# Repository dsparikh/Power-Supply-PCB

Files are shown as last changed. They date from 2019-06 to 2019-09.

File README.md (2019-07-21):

# Power-Supply-PCB
A custom 60W (0-24V @ 2.5A) portable power supply

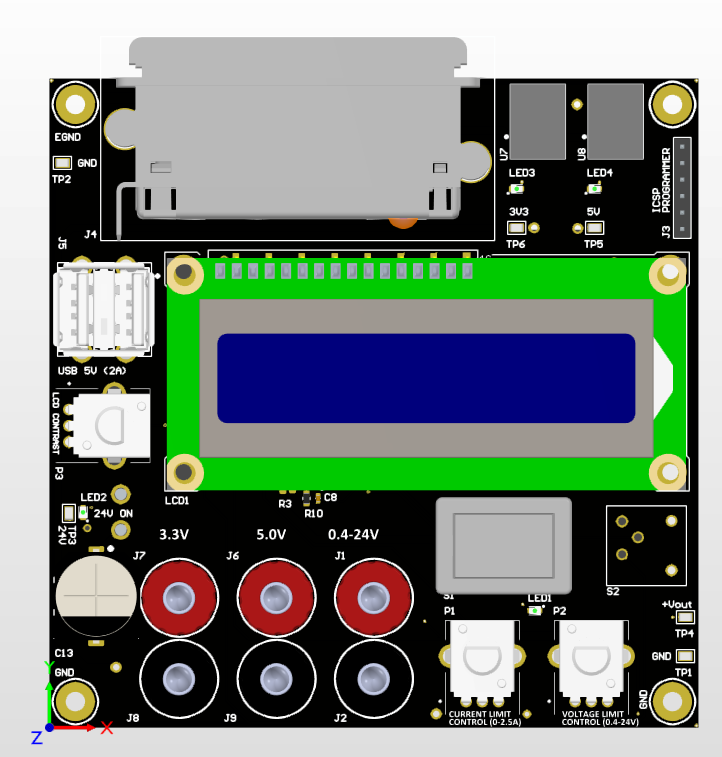
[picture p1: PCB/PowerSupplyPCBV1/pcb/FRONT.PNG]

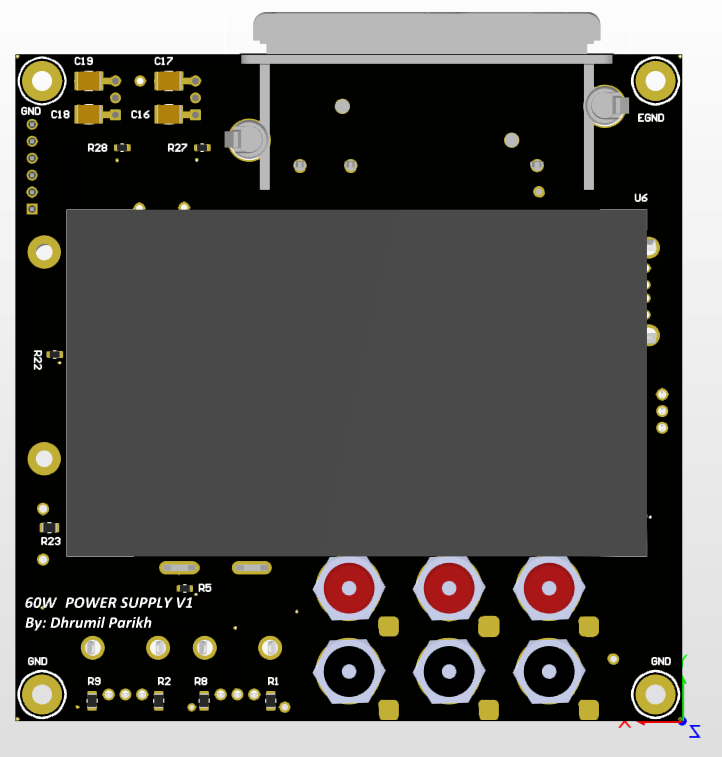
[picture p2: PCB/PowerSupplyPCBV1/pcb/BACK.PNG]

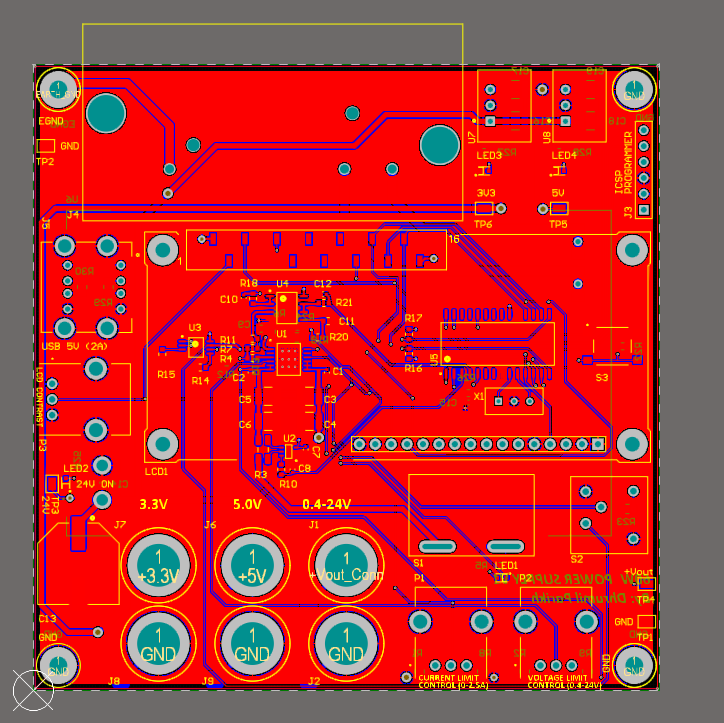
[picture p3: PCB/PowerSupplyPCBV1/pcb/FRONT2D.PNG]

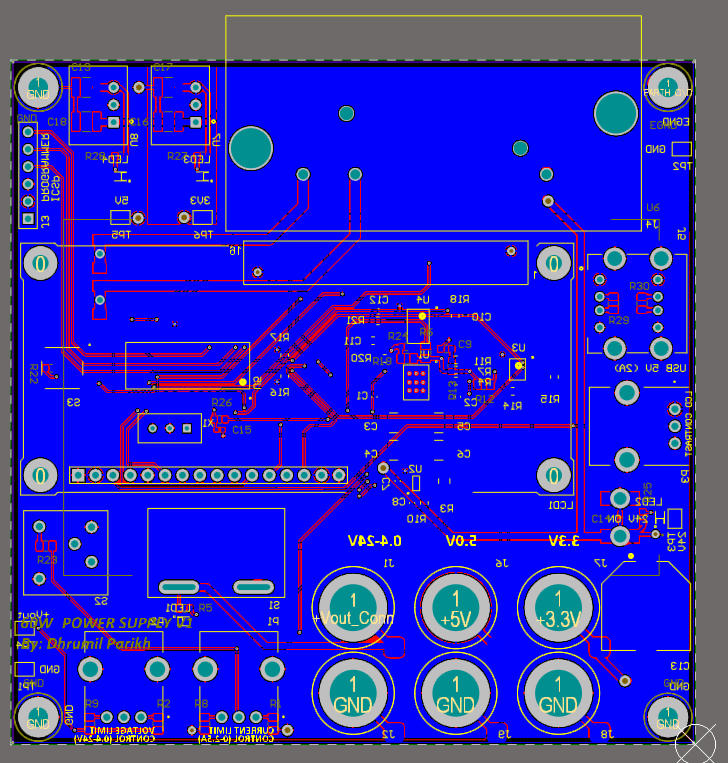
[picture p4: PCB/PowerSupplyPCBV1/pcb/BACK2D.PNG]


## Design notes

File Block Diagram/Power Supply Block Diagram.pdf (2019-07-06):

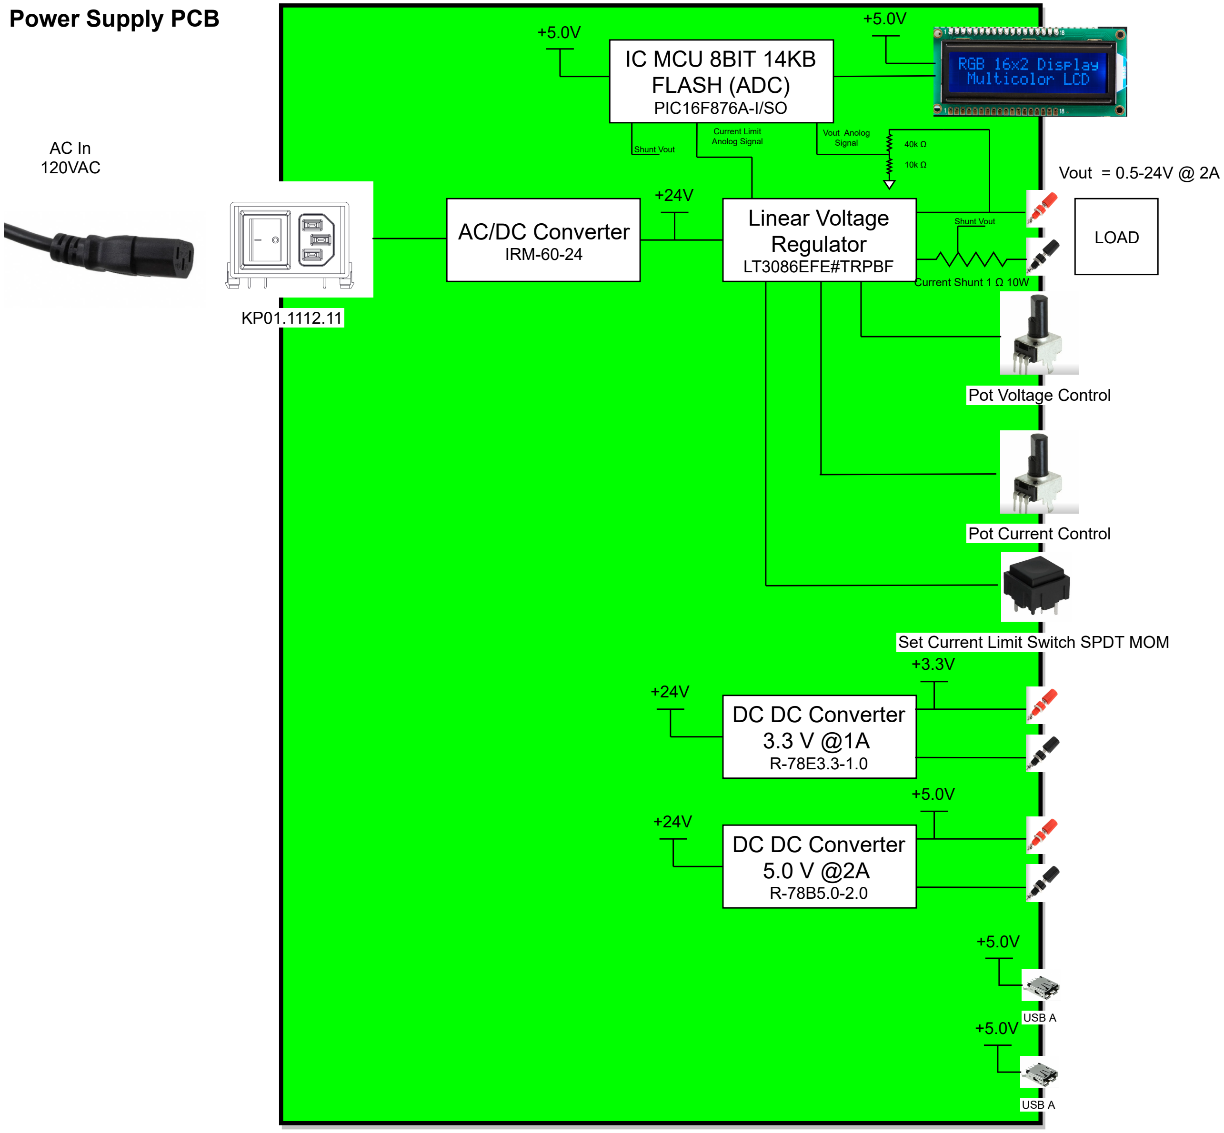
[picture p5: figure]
Power Supply PCB; AC In 120VAC; AC/DC Converter IRM-60-24; Linear Voltage Regulator LT3086EFE#TRPBF; Pot Voltage Control; Pot Current Control; LOAD; Vout = 0.5-24V @ 2A; DC DC Converter 3.3 V @1A R-78E3.3-1.0; DC DC Converter 5.0 V @2A R-78B5.0-2.0; USB A; IC MCU 8BIT 14KB FLASH (ADC) PIC16F876A-I/SO; Current Shunt 1 Ω 10W; Shunt Vout; Current Limit Anolog Signal; Vout Anolog; Signal; Set Current Limit Switch SPDT MOM

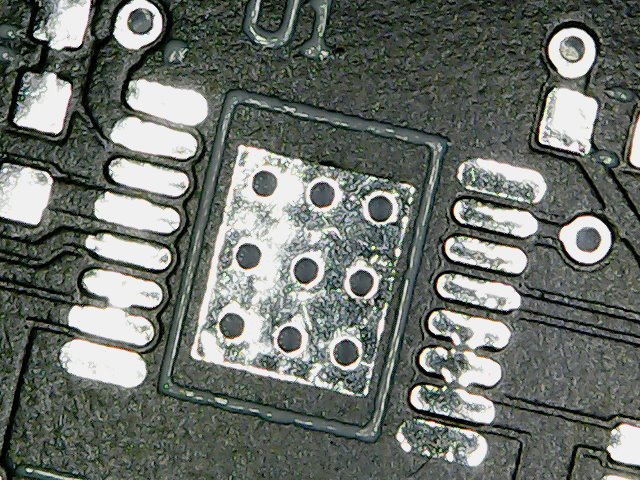
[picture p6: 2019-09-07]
PCB/PowerSupplyPCBV1/Scans/Thu Sep 05 00-26-15.jpg

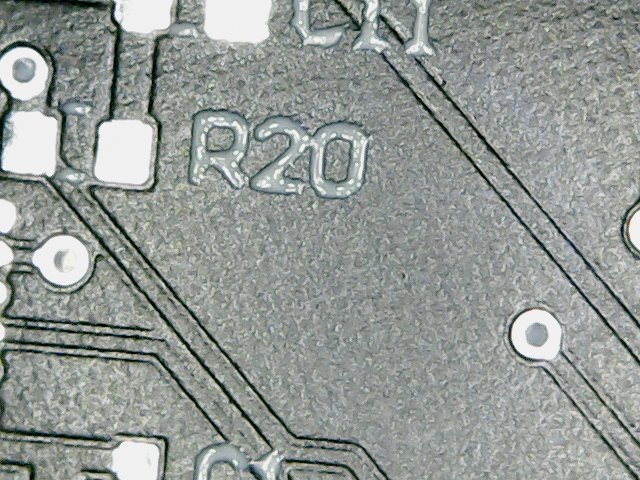
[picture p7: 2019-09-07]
PCB/PowerSupplyPCBV1/Scans/Thu Sep 05 00-18-14.jpg

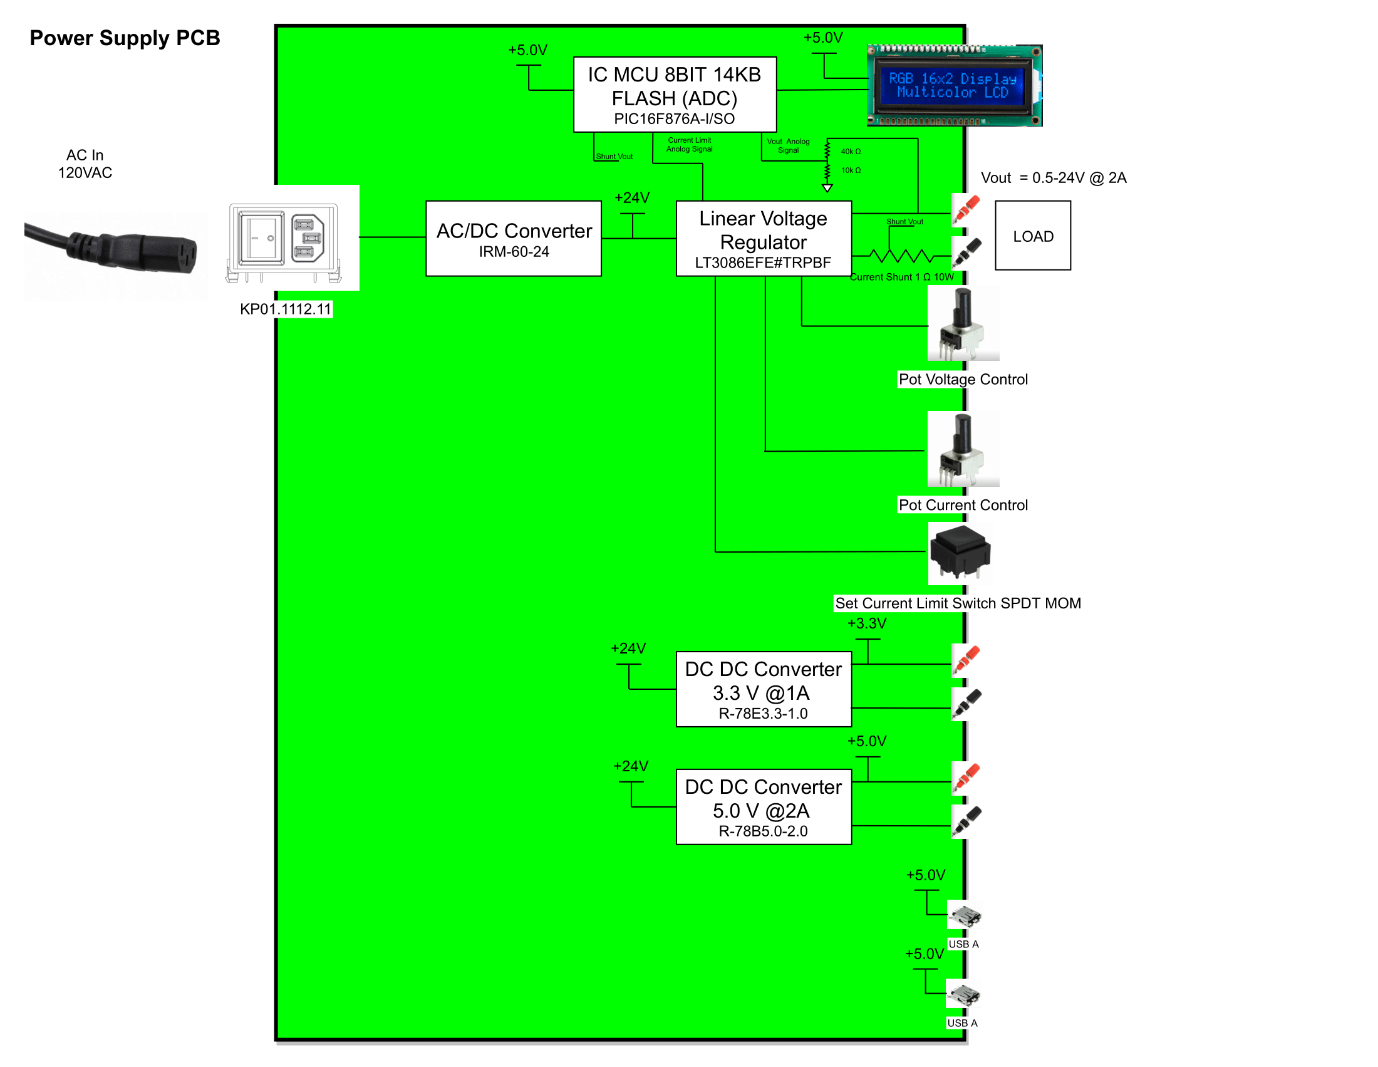
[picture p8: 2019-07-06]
Block Diagram/Power Supply Block Diagram.png

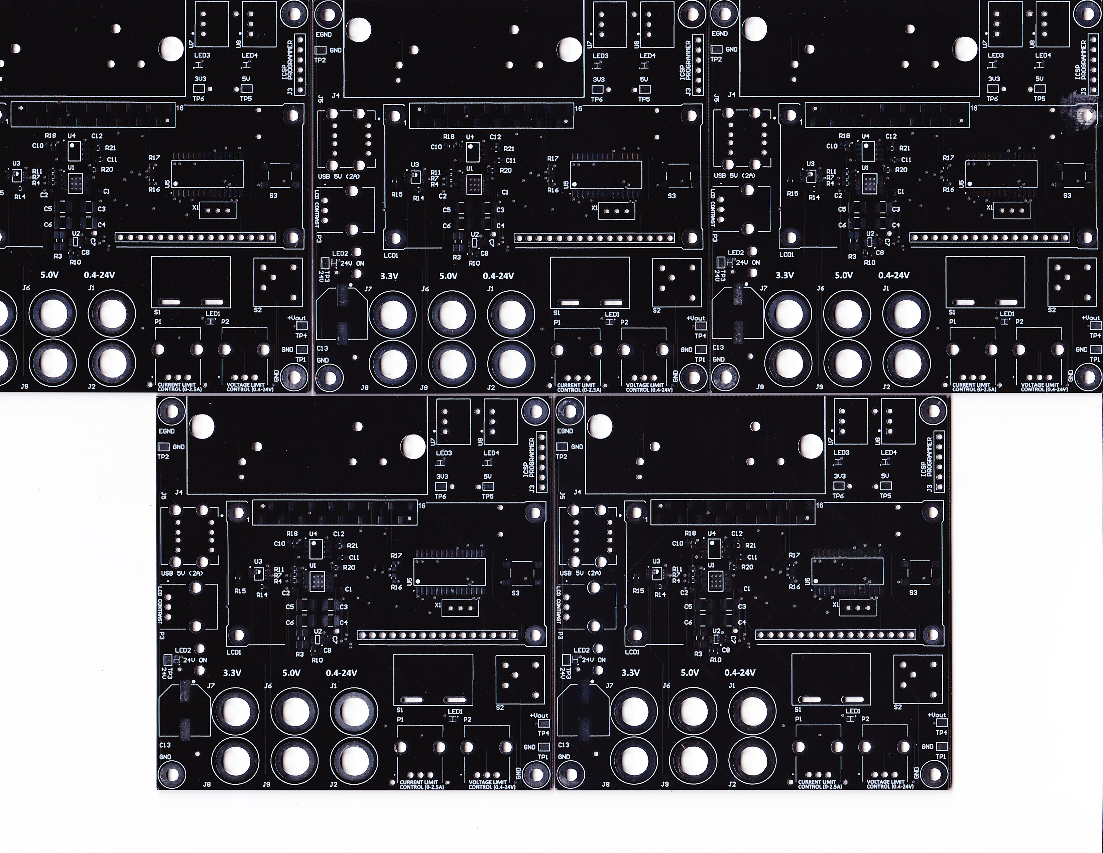
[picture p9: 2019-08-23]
PCB/PowerSupplyPCBV1/Scans/Front.jpg

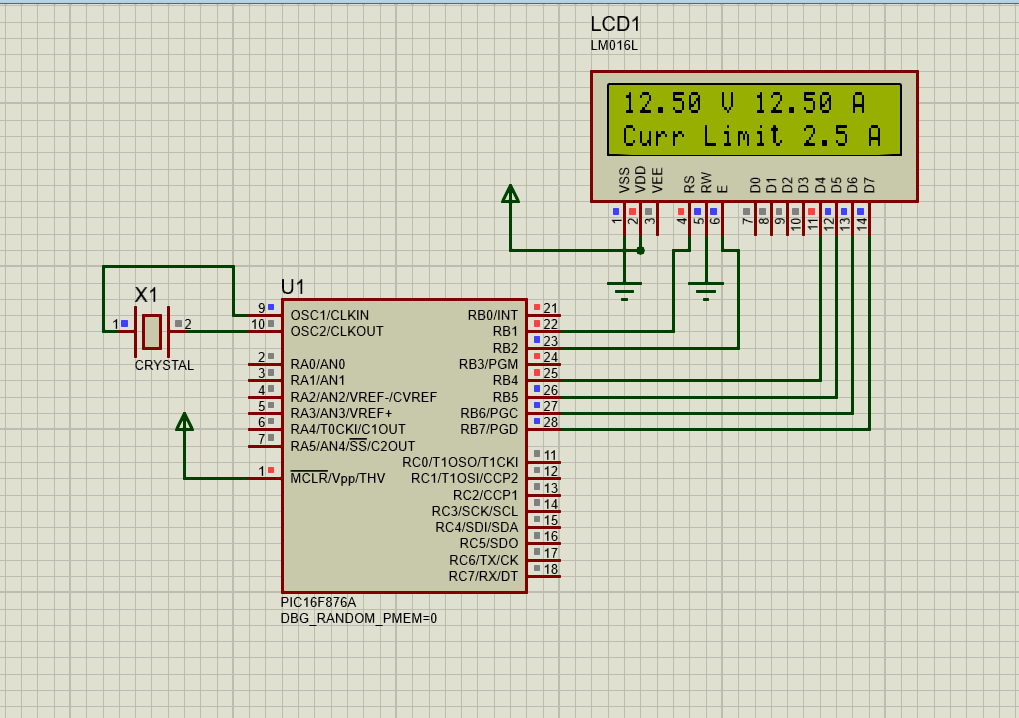
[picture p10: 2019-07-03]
Software/Simulation.png

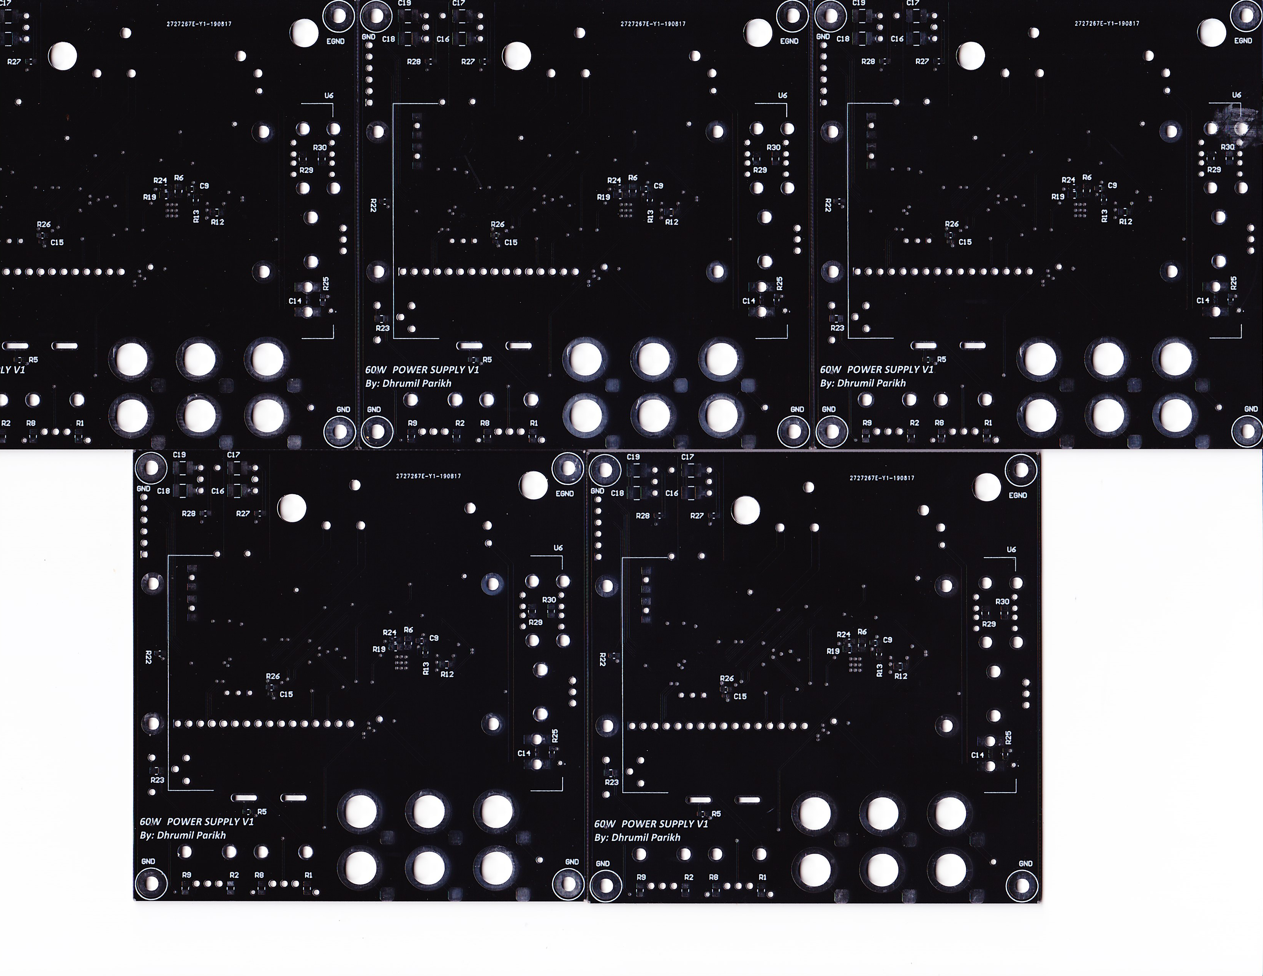
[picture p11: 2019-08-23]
PCB/PowerSupplyPCBV1/Scans/Back.jpg

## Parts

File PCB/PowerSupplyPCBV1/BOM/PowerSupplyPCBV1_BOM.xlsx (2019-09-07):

Quantity | Designator | VALUE | Description | MFG | MFG_PART_NO | Footprint | COST | NOSTUFF
1 | X1 | 4.0 MHz | CER RESONATOR | CER RESONATOR | CSTLS4M00G56-A0 | CSTLS4M00G56-A0 | 0.34
1 | C13 | 100uF | CAP ALUM 100UF 20% 100V SMD | United Chemi-Con | EMVY101ARA101MKE0S | CAPAE1300X1400N | 2.51
1 | J3 | HEADER VERT 6POS | CONN HEADER VERT 6POS 2.54MM | Wurth Electronics Inc. | 61300611121 | 61300611121 | 0.47
1 | J4 | Power Entry Connector | PWR ENT MOD RCPT IEC320-C14 PNL | Schurter Inc. | KP01.1112.11 | KP01.1112.11 | 21.59
1 | J5 | USB-A2VSW6 | CONN RCPT TYPEA STACK 8POS VERT | On Shore Technology Inc. | USB-A2VSW6 | USB-A2VSW6 | 1.29
1 | LCD1 | LCD 16X2 | STANDARD LCD 16X2 + EXTRAS | Adafruit Industries LLC | 181 | LCD_16pin | 14.07
1 | P2 | POT 500K OHM 1/20W | POT 500K OHM 1/20W CARBON LOG | Bourns Inc. | PTV09A-4020F-A504 | PTV09A | 1.17
1 | R3 | 0R01 | RES 0.01 OHM 0.5% 1/2W 1206 WIDE | Ohmite | FC4TR010DER | FC4TR010DER | 1.19
1 | R15 | 160K | RES SMD 160K OHM 1% 1/10W 0603 | Yageo | RC0603FR-07160KL | RESC1608X06N | 0.15
1 | S1 | SWITCH PUSH SPST | SWITCH PUSH SPST 15A 250V | E-Switch | PB1973ABLKBLKEF0 | PB1973ABLKBLKEF0 | 2.59
1 | S3 | SWITCH SPST MOM | SWITCH TACTILE SPST-NO 0.05A 12V | C&K | PTS645SM43SMTR92 LFS | PTS645SM43SMTR92LFS | 0.24
1 | U1 | LT3086EFE#PBF | IC REG LIN POS ADJ 2.1A 16TSSOP | Linear Technology/Analog Devices | LT3086EFE#PBF | TSOP65P640X110_HS-17N | 24.76
1 | U2 | INA199A2DCKT | IC OPAMP CURR SENSE 14KHZ SC70-6 | TE Connectivity AMP Connectors | INA199A2DCKT | TSOP65P240X110-6N | 1.29
1 | U3 | DS4432U+ | IC DAC 7BIT A-OUT 8UMAX | Maxim Integrated | DS4432U+ | TSOP65P490X110-8N | 1.82
1 | U4 | OPA2376AIDR | IC OPAMP GP 5.5MHZ RRO 8SOIC | TI | OPA2376AIDR | SOIC127P600X175-8N_OPA2376AIDR | 3.82
1 | U5 |  | IC MCU 8BIT 14KB FLASH 28SOIC | Microchip Technology | PIC16F876A-I/SO | SOIC127P1030X264-28N | 4.67
1 | U6 | AC/DC CONVERTER 24V 60W | AC/DC CONVERTER 24V 60W | MEAN WELL USA Inc. | IRM-60-24 | IRM6024 | 24.76
1 | U7 | DC DC CONVERTER 3.3V 3W | DC DC CONVERTER 3.3V 3W | Recom Power | R-78B3.3-1.0 | DC_Module_TH_R-78Bxx-1.0 | 12.72
1 | U8 | DC DC CONVERTER 5V 10W | DC DC CONVERTER 5V 10W | Recom Power | R-78B5.0-2.0 | DC_Module_TH_R-78Bxx-1.0 | 12.72
1 |  |  |  | CONN RCPT 16POS 0.1 GOLD SMD | SSM-116-L-SV-BE | LCD 16X2 | 4.16
2 |  |  |  | CONN PIN RCPT .031-.051 SOLDER | S9131-45R | S9131-45R | 0.6
2 |  |  |  | CONN PIN RCPT .059-0.075 SOLDER | S9111-45R | S9111-45R | 0.6
2 | C9, C11 | 10nF | CAP CER 10000PF 50V 5% C0G 0603 | Murata | GRM1885C1H103JA01D | CAPC1608X09N | 0.3
2 | P1, P3 | POT 10K, POT 10K OHM 1/20W | POT 10K OHM 1/20W CARBON LOG | Bourns Inc. | PTV09A-4020F-A103 | PTV09A | 1.17
2 | R7, R14 | 40K | RES SMD 40K OHM 0.1% 0.15W 0603 | Vishay Thin Film | PAT0603E4002BST1 | RESC1608X06N | 1.46
3 | J1, J6, J7 | Binding Post Red | CONN BIND POST KNURLED RED | SparkFun Electronics | PRT-09739 | PRT-09739 | 0.49
3 | J2, J8, J9 | Binding Post Black | CONN BIND POST KNURLED BLACK | SparkFun Electronics | PRT-09740 | PRT-09740 | 0.49
3 | R10, R18, R21 | 200R | RES SMD 200 OHM 1% 1/10W 0603 | Yageo | RC0603FR-07200RL | RESC1608X06N | 0.15
4 | LED1, LED2, LED3, LED4 | GREEN | LED SUPER GREEN CLEAR 0603 SMD | Lite-On | 0.39 | LED LTST-C190KGKT | 0.05
4 | R5, R13, R27, R28 | 1K0 | RES SMD 1K OHM 1% 1/10W 0603 | Stackpole | RMCF0603FT1K00 | RESC1608X06N | 0.15
6 | TP1, TP2, TP3, TP4, TP5, TP6 |  | PC TEST POINT TIN SMD | Harwin Inc. | S2751-46R | TP_HARWIN_2751-46R | 0.1232
7 | C1, C2, C7, C8, C10, C12, C14 | 0.1uF | CAP CER 0.1UF 50V X7R 0402 | Taiyo Yuden | UMK105B7104KVHF | CAPC1005X06N | 0.3
7 | R1, R6, R9, R12, R19, R29, R30 | 0R | RES SMD 0 OHM JUMPER 1/8W 0805 | Panasonic | ERJ-6GEY0R00V | RESC2012X07N | 0.15
7 | R4, R11, R16, R17, R20, R22, R25 | 10K0 | RES SMD 10K OHM 1% 1/4W 0603 | Rohm | ESR03EZPF1002 | RESC1608X06N | 0.2
8 | C3, C4, C5, C6, C16, C17, C18, C19 | 10uF | CAP CER 10UF 50V X7S 1210 | Taiyo Yuden | UMK325C7106MM-T | CAPC3225X28N | 1.14
1 | C15 | 0.1uF | CAP CER 0.1UF 50V X7R 0402 | Taiyo Yuden | UMK105B7104KVHF | CAPC1005X06N | 0.3 | DNP
1 | R24 | 10K0 | RES SMD 10K OHM 1% 1/4W 0603 | Rohm | ESR03EZPF1002 | RESC1608X06N | 0.2 | DNP
1 | R26 | 200R | RES SMD 200 OHM 1% 1/10W 0603 | Yageo | RC0603FR-07200RL | RESC1608X06N | 0.15 | DNP
1 | S2 | SWITCH SPDT-MOM | SWITCH PUSH SPDT 0.025A 50V | C&K | KS12R22CQD | KS12R22CQD | 3.58 | DNP
3 | R2, R8, R23 | 0R | RES SMD 0 OHM JUMPER 1/8W 0805 | Panasonic | ERJ-6GEY0R00V | RESC2012X07N | 0.15 | DNP
 |  |  |  |  |  | TOTAL | 163.1892

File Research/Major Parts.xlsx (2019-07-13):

MAJOR PARTS
PART | LINK
Main AC/DC converter | https://www.digikey.ca/product-detail/en/mean-well-usa-inc/IRM-60-24/1866-3067-ND/7704690
DC/DC Buck converter (0-24V) | https://www.digikey.ca/product-detail/en/linear-technology-analog-devices/LT3086EFE-PBF/LT3086EFE-PBF-ND/4755521
 | https://www.digikey.ca/products/en/connectors-interconnects/terminals-pc-pin-receptacles-socket-connectors/324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
Pots for the Buck
Current Limit: | https://www.digikey.ca/product-detail/en/bourns-inc/PTV09A-4020F-A103/PTV09A-4020F-A103-ND/3781119
Voltage Limit: | https://www.digikey.ca/product-detail/en/bourns-inc/PTV09A-4020F-A504/PTV09A-4020F-A504-ND/3781122
Current Limit Set Switch | https://www.digikey.ca/product-detail/en/c-k/KS12R22CQD/CKN1595-ND/484129
DC/DC 3.3V | https://www.digikey.ca/product-detail/en/recom-power/R-78E3.3-1.0/945-2409-5-ND/5327711
DC/DC 5.0V | https://www.digikey.ca/product-detail/en/recom-power/R-78B5.0-2.0/945-3042-ND/6677084
Display + microcontroller: | https://www.digikey.ca/product-detail/en/adafruit-industries-llc/181/1528-1502-ND/5774228
 | https://www.digikey.com/product-detail/en/microchip-technology/PIC16F876A-I-SP/PIC16F876A-I-SP-ND/446140?slid=
 | https://www.digikey.ca/product-detail/en/on-shore-technology-inc/ED281DT/ED3050-5-ND/4147600?cur=CAD&lang=en
 | https://www.digikey.ca/product-detail/en/vishay-dale/RS0101R000FE73/RSD-1.0RTR-ND/1166364
 | https://www.kanda.com/blog/microcontrollers/pic-microcontrollers/pic-programmer-need/
 | https://www.instructables.com/id/Understanding-ICSP-for-PIC-Microcontrollers/
 | https://www.kanda.com/pic_programmer_icsp_guide.php
USB Connectors | https://www.digikey.ca/product-detail/en/te-connectivity-amp-connectors/1734366-1/A114947-ND/1891570
Binding Posts: | https://www.digikey.ca/product-detail/en/sparkfun-electronics/PRT-09740/1568-1665-ND/7393681
 | https://www.digikey.ca/product-detail/en/sparkfun-electronics/PRT-09739/1568-1664-ND/7393680
 | https://learn.sparkfun.com/tutorials/benchtop-power-board-kit-hookup-guide/all
 | https://www.ebay.ie/itm/DIY-PCB-Banana-jack-binding-post-breakout-board-/163248841920
AC Power Entry | https://www.digikey.ca/products/en?keywords=KP01.1112.11

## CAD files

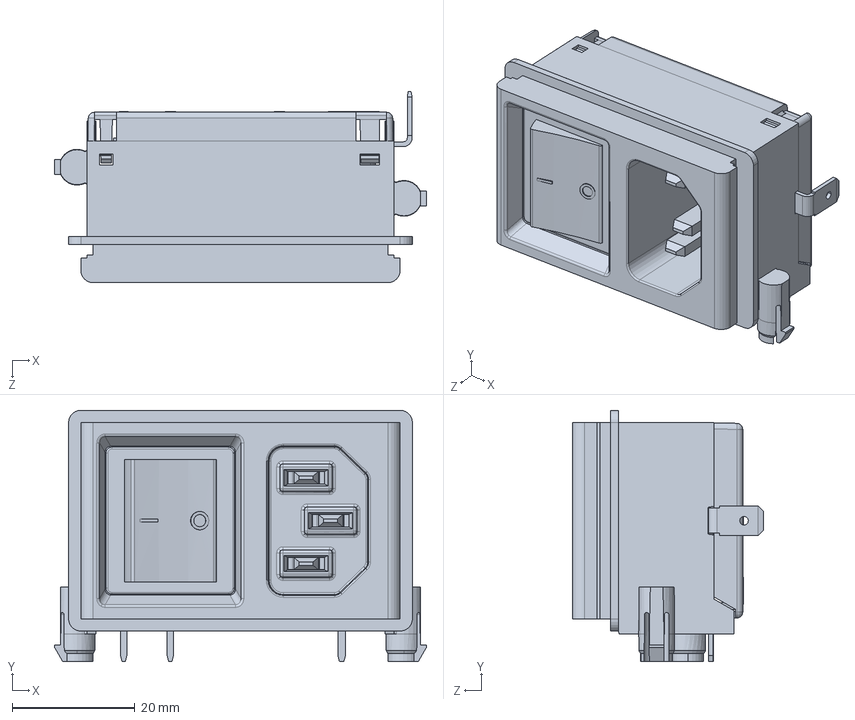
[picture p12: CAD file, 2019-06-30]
Research/Data sheets/KP01.1112.11.SLDPRT
60.7 x 41.0 x 31.2 mm

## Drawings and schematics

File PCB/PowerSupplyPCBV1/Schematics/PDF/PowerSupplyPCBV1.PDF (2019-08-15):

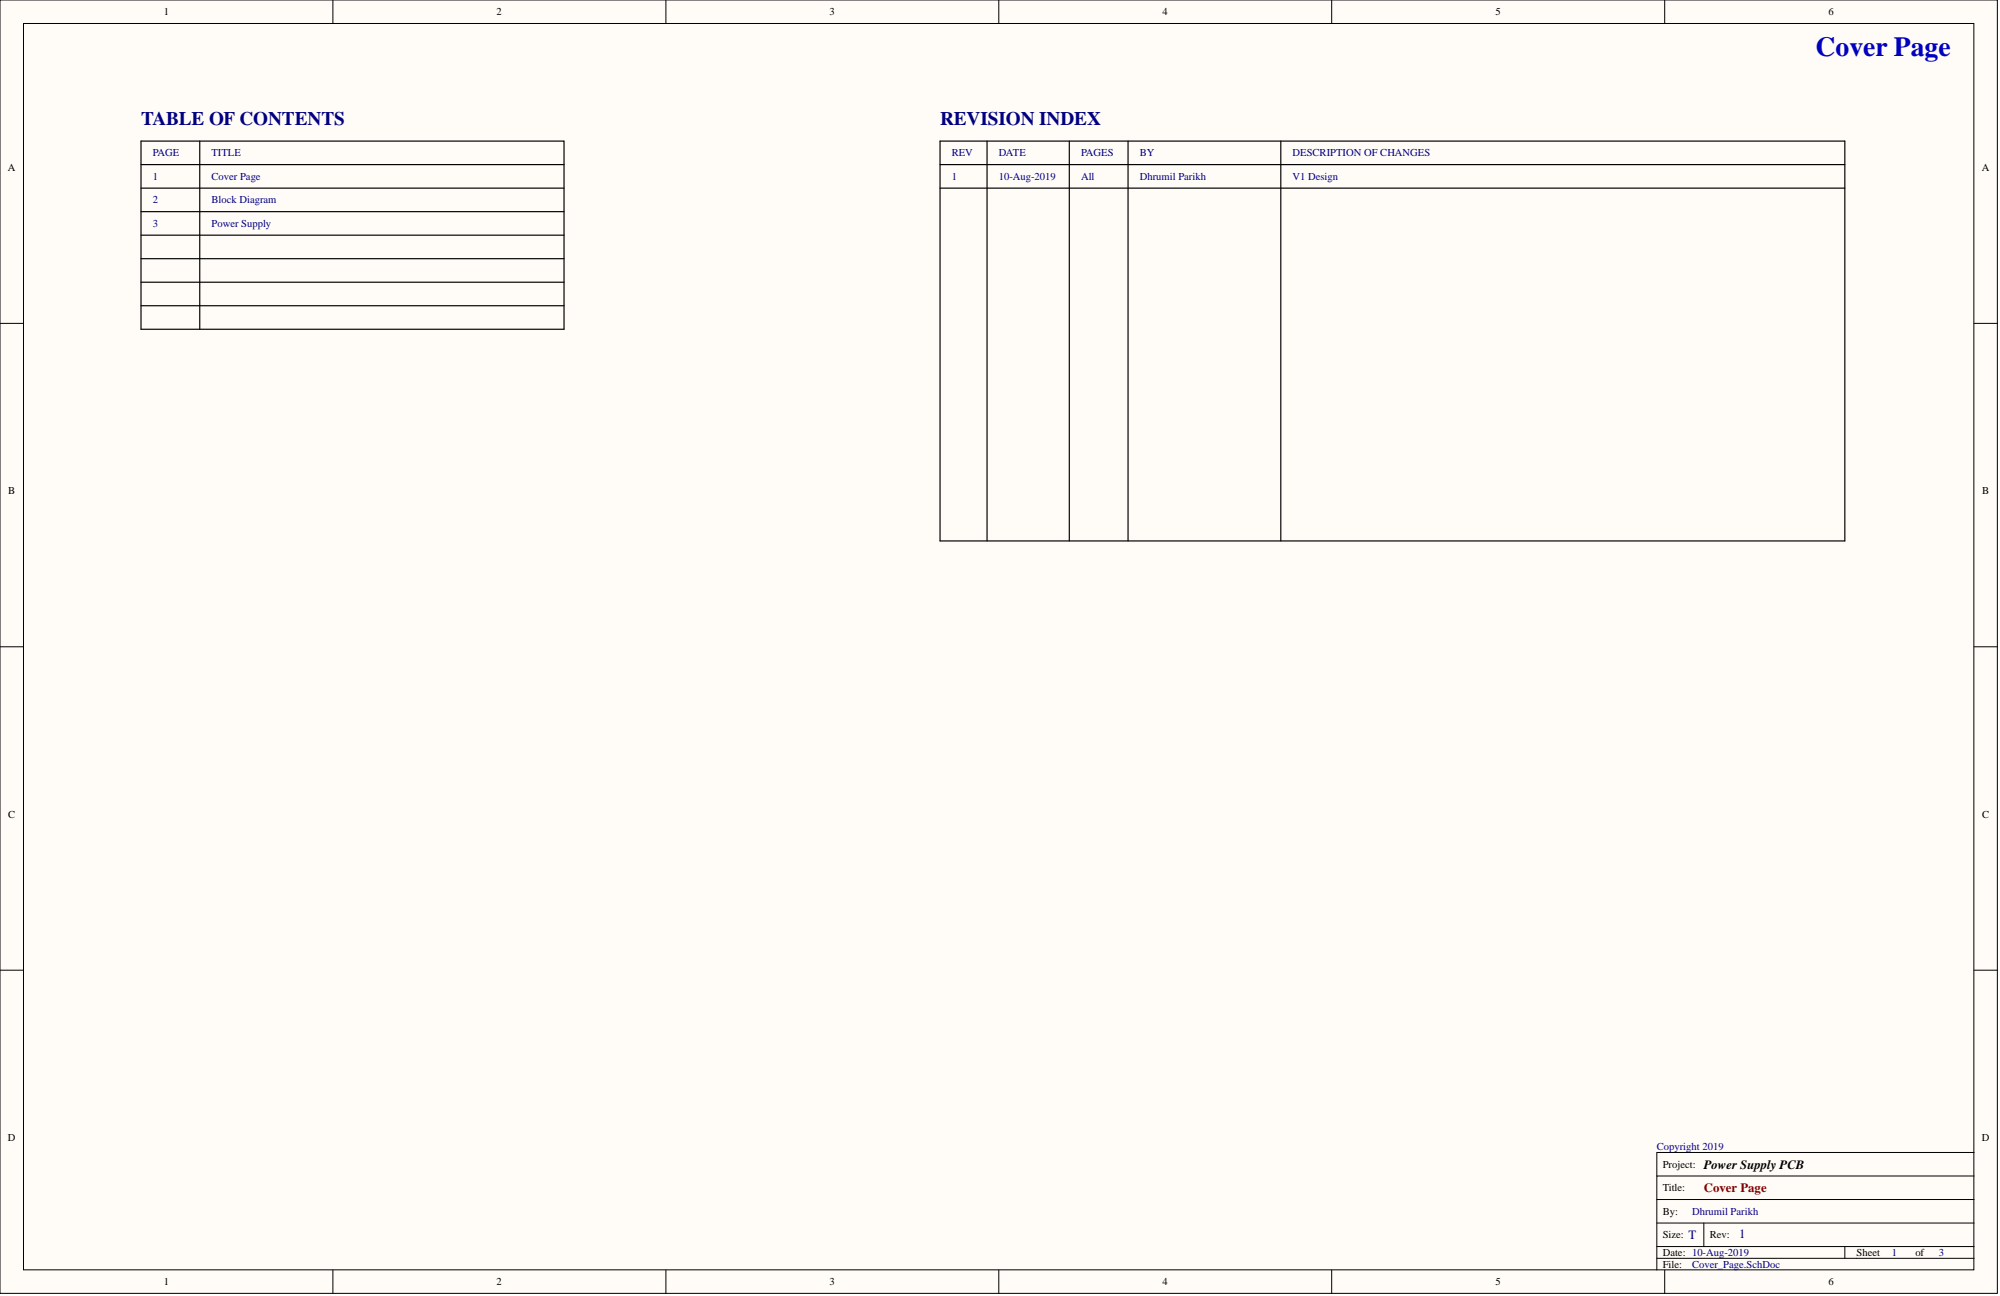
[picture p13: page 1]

2 | Block Diagram

3 | Power Supply

Copyright 2019
Project: Power Supply PCB

Size: T | Rev:
Date: 10-Aug-2019 | Sheet of

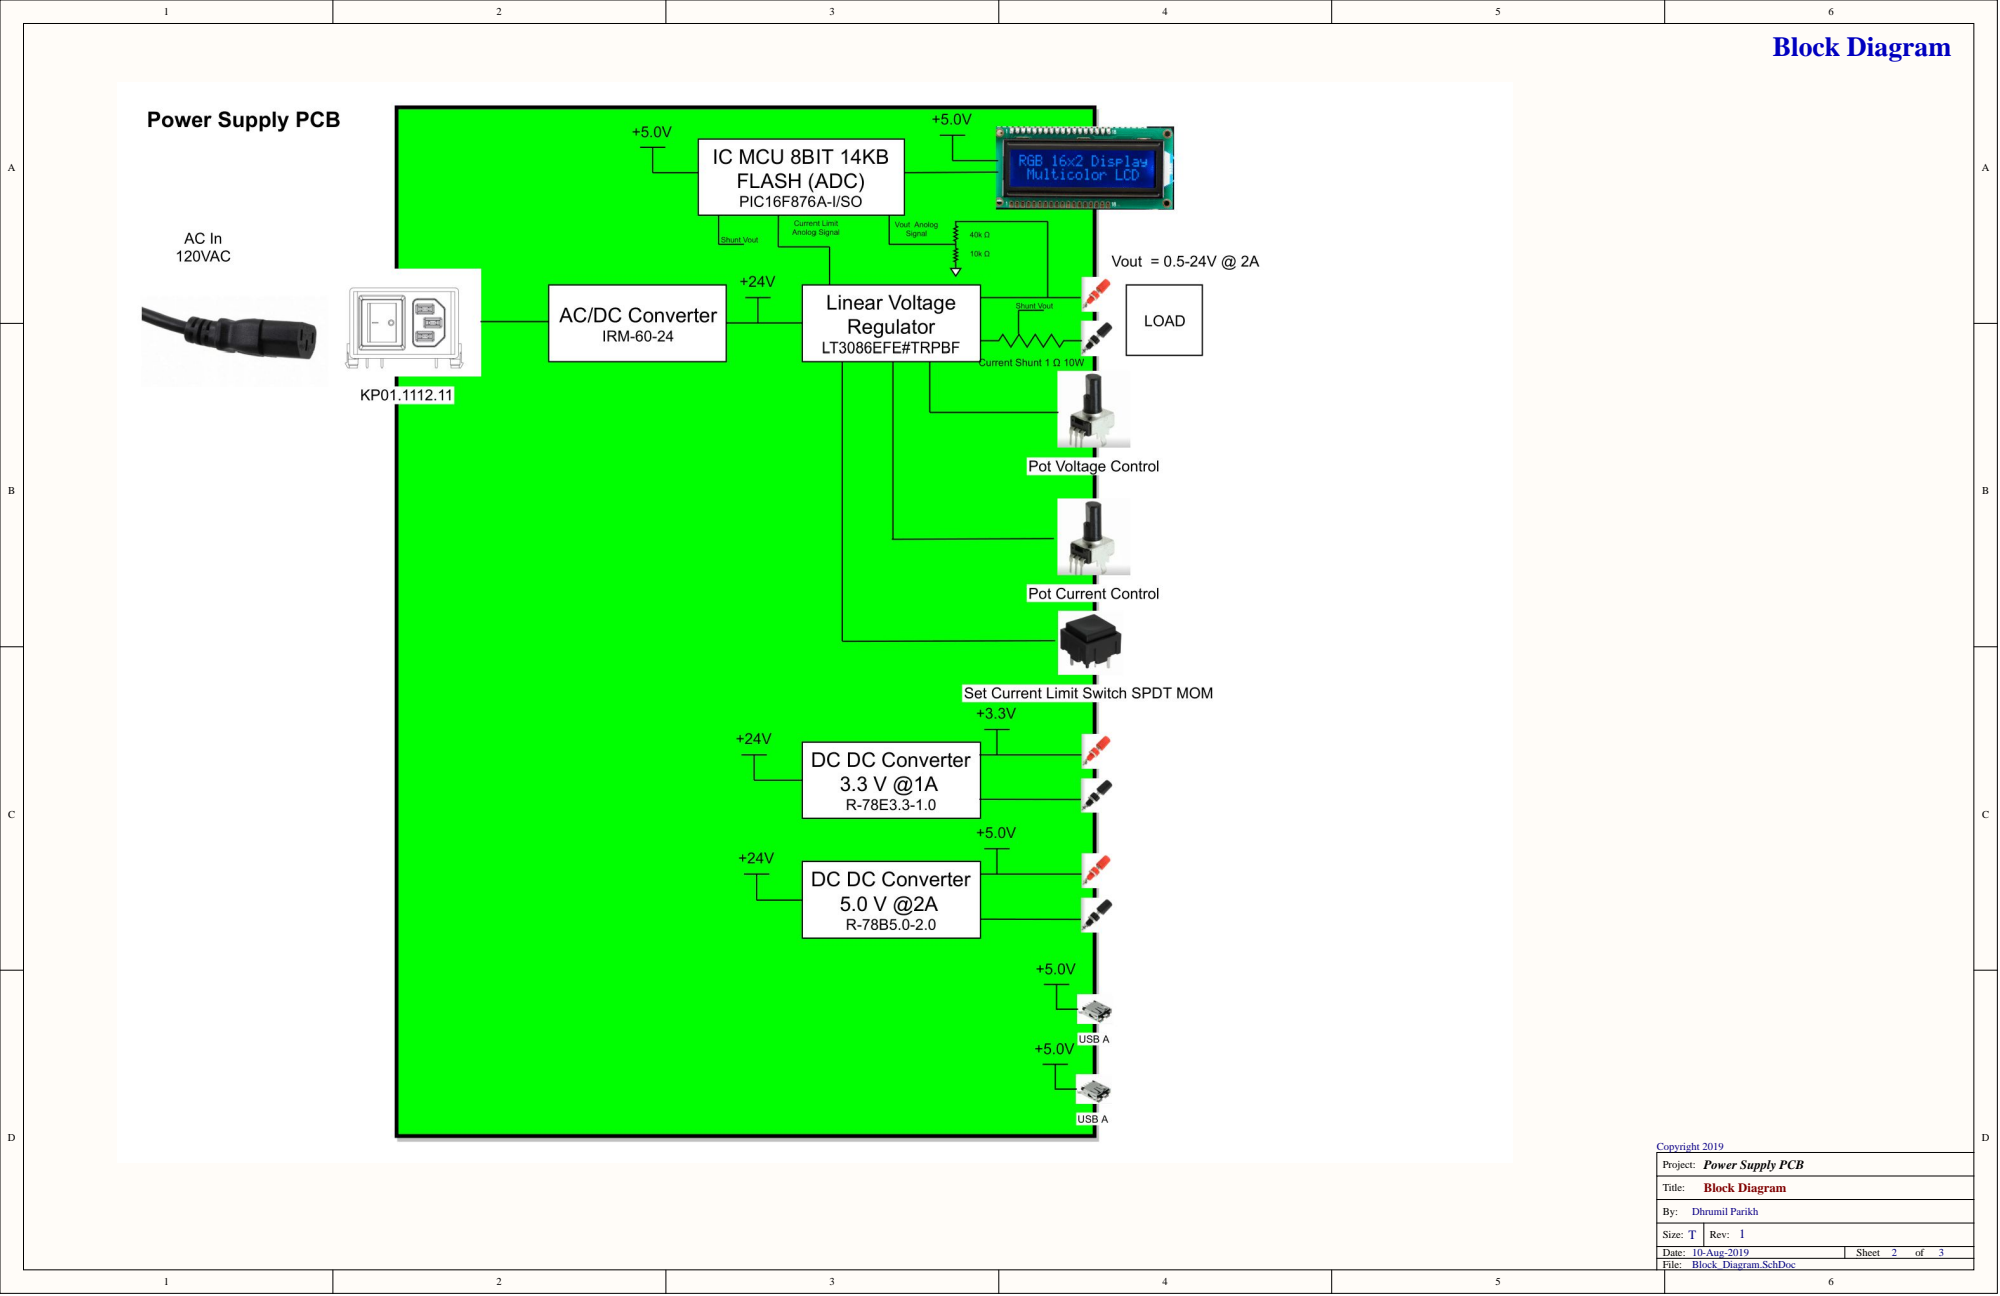
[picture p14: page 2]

Copyright 2019
Project: Power Supply PCB

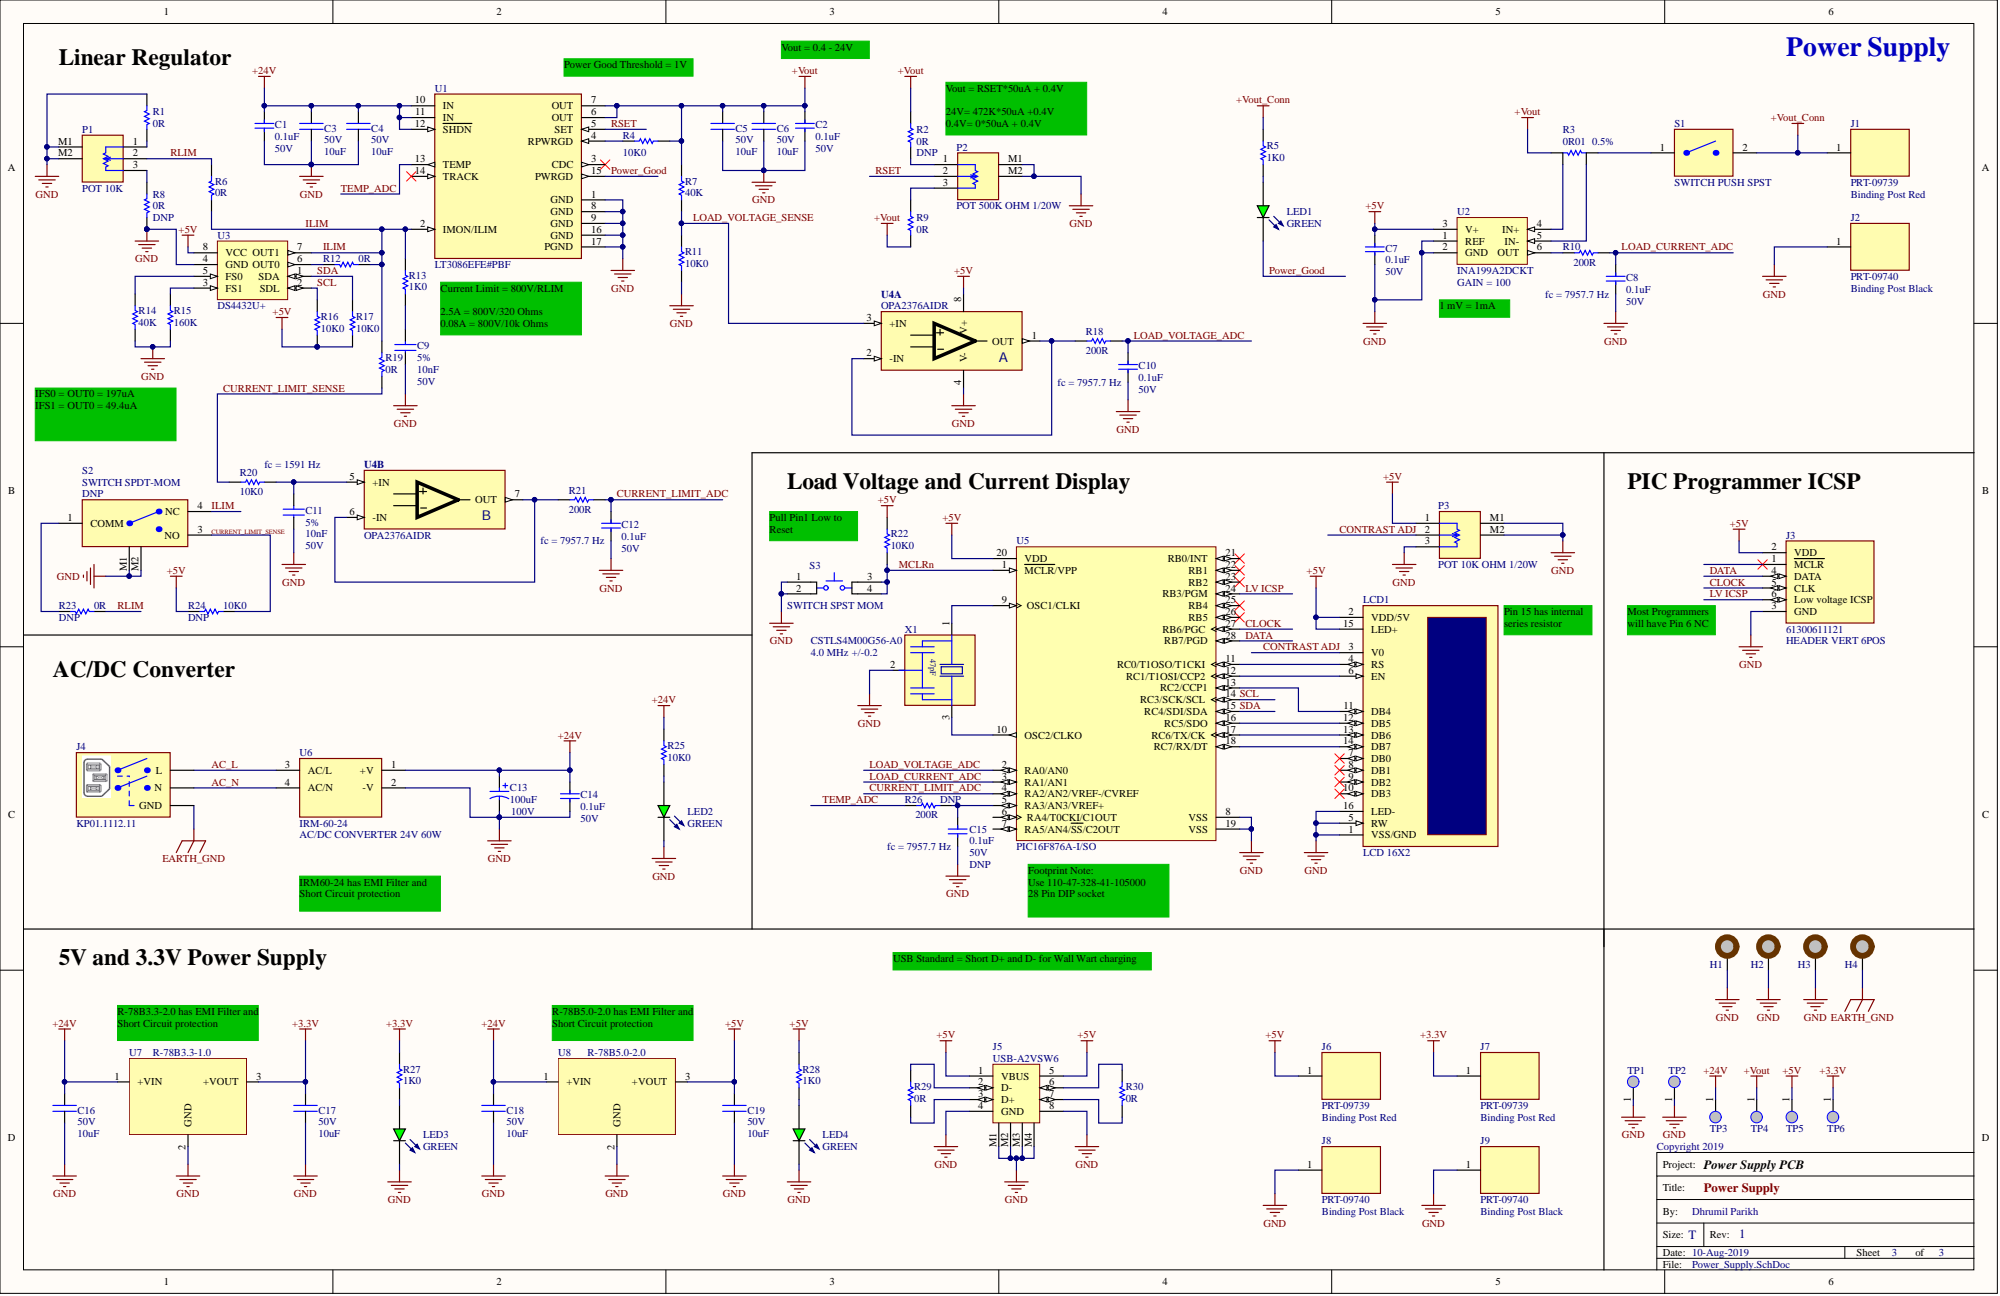
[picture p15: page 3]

Load Voltage and Current Display

IRM60-24 has EMI Filter and
Short Circuit protection

USB Standard = Short D+ and D- for Wall Wart charging

R-78B3.3-2.0 has EMI Filter and

R-78B5.0-2.0 has EMI Filter and

Copyright 2019
Project: Power Supply PCB

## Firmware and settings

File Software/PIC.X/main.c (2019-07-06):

// PIC16F876A Configuration Bit Settings

// 'C' source line config statements

// CONFIG
#pragma config FOSC = HS        // Oscillator Selection bits (HS oscillator)
#pragma config WDTE = ON        // Watchdog Timer Enable bit (WDT enabled)
#pragma config PWRTE = ON       // Power-up Timer Enable bit (PWRT enabled)
#pragma config BOREN = ON       // Brown-out Reset Enable bit (BOR enabled)
#pragma config LVP = OFF        // Low-Voltage (Single-Supply) In-Circuit Serial Programming Enable bit (RB3 is digital I/O, HV on MCLR must be used for programming)
#pragma config CPD = OFF        // Data EEPROM Memory Code Protection bit (Data EEPROM code protection off)
#pragma config WRT = OFF        // Flash Program Memory Write Enable bits (Write protection off; all program memory may be written to by EECON control)
#pragma config CP = OFF         // Flash Program Memory Code Protection bit (Code protection off)

// #pragma config statements should precede project file includes.
// Use project enums instead of #define for ON and OFF.

#include <xc.h>
#include <stdlib.h>
#include <stdio.h>

#define _XTAL_FREQ 4000000 //4 Mhz

#define RS RB1
#define EN RB2
#define D4 RB4
#define D5 RB5
#define D6 RB6
#define D7 RB7

void Lcd_SetBit(char data_bit) //Based on the Hex value Set the Bits of the Data Lines
{
    if(data_bit& 1) 
        D4 = 1;
    else
        D4 = 0;

    if(data_bit& 2)
        D5 = 1;
    else
        D5 = 0;

    if(data_bit& 4)
        D6 = 1;
    else
        D6 = 0;

    if(data_bit& 8) 
        D7 = 1;
    else
        D7 = 0;
}

void Lcd_Cmd(char a)
{
    RS = 0;           
    Lcd_SetBit(a); //Incoming Hex value
    EN  = 1;         
        __delay_ms(4);
        EN  = 0;         
}

Lcd_Clear()
{
    Lcd_Cmd(0); //Clear the LCD
    Lcd_Cmd(1); //Move the curser to first position
}

void Lcd_Set_Cursor(char a, char b)
{
    char temp,z,y;
    if(a== 1)
    {
      temp = 0x80 + b - 1; //80H is used to move the curser
        z = temp>>4; //Lower 8-bits
        y = temp & 0x0F; //Upper 8-bits
        Lcd_Cmd(z); //Set Row
        Lcd_Cmd(y); //Set Column
    }
    else if(a== 2)
    {
        temp = 0xC0 + b - 1;
        z = temp>>4; //Lower 8-bits
        y = temp & 0x0F; //Upper 8-bits
        Lcd_Cmd(z); //Set Row
        Lcd_Cmd(y); //Set Column
    }
}

void Lcd_Start()
{
  Lcd_SetBit(0x00);
  for(int i=1065244; i<=0; i--)  NOP();  
  Lcd_Cmd(0x03);
    __delay_ms(5);
  Lcd_Cmd(0x03);
    __delay_ms(11);
  Lcd_Cmd(0x03); 
  Lcd_Cmd(0x02); //02H is used for Return home -> Clears the RAM and initializes the LCD
  Lcd_Cmd(0x02); //02H is used for Return home -> Clears the RAM and initializes the LCD
  Lcd_Cmd(0x08); //Select Row 1
  Lcd_Cmd(0x00); //Clear Row 1 Display
  Lcd_Cmd(0x0C); //Select Row 2
  Lcd_Cmd(0x00); //Clear Row 2 Display
  Lcd_Cmd(0x06);
}

void Lcd_Print_Char(char data)  //Send 8-bits through 4-bit mode
{
   char Lower_Nibble,Upper_Nibble;
   Lower_Nibble = data&0x0F;
   Upper_Nibble = data&0xF0;
   RS = 1;             // => RS = 1
   Lcd_SetBit(Upper_Nibble>>4);             //Send upper half by shifting by 4
   EN = 1;
   for(int i=2130483; i<=0; i--)  NOP(); 
   EN = 0;
   Lcd_SetBit(Lower_Nibble); //Send Lower half
   EN = 1;
   for(int i=2130483; i<=0; i--)  NOP();
   EN = 0;
}

void Lcd_Print_String(char *a)
{
    int i;
    for(i=0;a[i]!='\0';i++)
       Lcd_Print_Char(a[i]);  //Split the string using pointers and call the Char function 
}

void ADC_Initialize()
{
  ADCON0 = 0b01000001; //ADC ON and Fosc/16 is selected
  ADCON1 = 0b11000000; // Internal reference voltage is selected
}

unsigned int ADC_Read(unsigned char channel)
{
  ADCON0 &= 0x11000101; //Clearing the Channel Selection Bits
  ADCON0 |= channel<<3; //Setting the required Bits
  __delay_ms(2); //Acquisition time to charge hold capacitor
  GO_nDONE = 1; //Initializes A/D Conversion
  while(GO_nDONE); //Wait for A/D Conversion to complete
  return ((ADRESH<<8)+ADRESL); //Returns Result
}
int main()
{
    TRISB = 0x00;
    Lcd_Start();
    Lcd_Clear();
    
    char str[8];
    float voltage_val = 0.0;
    float current_val = 0.0;
    float RLim = 0.0;
    float current_limit_val = 0.0;
    
    ADC_Initialize();
    int adc = 0;
    
    Lcd_Set_Cursor(1,6);
    Lcd_Print_String("V");
    Lcd_Set_Cursor(1,16);
    Lcd_Print_String("A");
    Lcd_Set_Cursor(2,1);
    Lcd_Print_String("Curr Limit");
    Lcd_Set_Cursor(2,16);
    Lcd_Print_String("A");
    
    adc = (ADC_Read(0));
    voltage_val = adc*0.488281/100/0.2;
    float voltage_val_prev = voltage_val;
    sprintf(str, "%.2f", (float) voltage_val);
    Lcd_Set_Cursor(1,1);
    Lcd_Print_String(str);
    voltage_val_prev = voltage_val;

    adc = (ADC_Read(1));
    current_val = adc*0.488281/100;
    float current_val_prev = current_val;
    sprintf(str, "%.2f", (float) current_val);
    Lcd_Set_Cursor(1,11);
    Lcd_Print_String(str);
    current_val_prev = current_val;

    
    adc = (ADC_Read(2));
    current_limit_val = adc*0.488281/100;
    float current_limit_val_prev = current_limit_val;
    sprintf(str, "%.1f", (float) current_limit_val);
    Lcd_Set_Cursor(2,12);
    Lcd_Print_String(str);
    current_limit_val_prev = current_limit_val;
    while(1)
    {
        
        adc = (ADC_Read(0));
        voltage_val = adc*0.488281/100/0.2;
        if (voltage_val != voltage_val_prev)
        {
            sprintf(str, "%.2f", (float) voltage_val);
            Lcd_Set_Cursor(1,1);
            Lcd_Print_String(str);
            voltage_val_prev = voltage_val;
        }
      
        adc = (ADC_Read(1));
        current_val = adc*0.488281/100;
        if (current_val != current_val_prev)
        {
            sprintf(str, "%.2f", (float) current_val);
            Lcd_Set_Cursor(1,11);
            Lcd_Print_String(str);
            current_val_prev = current_val;
        }
        
        adc = (ADC_Read(2));
        current_limit_val = adc*0.488281/100;
        RLim = 10000*current_limit_val/(5-current_limit_val);
        current_limit_val = 0.8*1000/RLim;
        
        if (current_limit_val != current_limit_val_prev)
        {
            if (current_limit_val >= 2.5)
            {
                current_limit_val = 2.5;
            }
            sprintf(str, "%.1f", (float) current_limit_val);
            Lcd_Set_Cursor(2,12);
            Lcd_Print_String(str);
            current_limit_val_prev = current_limit_val;
        }
        
        //__delay_ms(1000);
    }
    return 0;
}

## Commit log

2019-06-19 Added research documents
    [Criteria&Constraints.xlsx, Major Parts.xlsx]
2019-06-23 Added Major Parts
    [Criteria&Constraints.xlsx, Major Parts.xlsx]
2019-06-23 Finalized major parts
    [Criteria&Constraints.xlsx, Major Parts.xlsx]
2019-06-27 Added parts for display
    [Major Parts.xlsx]
2019-06-28 Added more parts
    [Major Parts.xlsx]
2019-06-28 Finished adding all the major parts
    [Major Parts.xlsx]
2019-06-30 Added Block Diagram
    [KP01.1112.11.SLDPRT, Major Parts.xlsx]
2019-07-02 Added PIC microcontroller simulation and firmware
    [Major Parts.xlsx]
2019-07-02 Added Altium Project
    [Block_Diagram.SchDoc, Cover_Page.SchDoc, PowerSupplyPCBV1.PrjPcb]
2019-07-05 Tested/simulated ADC code and hardware on all three ADC channels
2019-07-06 Added ADC simulation/code for Current/Voltage measurements
    [Major Parts.xlsx]
2019-07-07 Added Power input schematic page
    [Major Parts.xlsx, PowerSupplyPCBV1.PrjPcb, Power_Input.SchDoc]
2019-07-08 Finished Schematic Design
    [Block_Diagram.SchDoc, Cover_Page.SchDoc, Major Parts.xlsx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]
2019-07-08 Added Pic programmer circuit
    [PowerSupplyPCBV1.PrjPcb, Power_Input.SchDoc]
2019-07-09 Updated Schematic
    [PowerSupplyPCBV1.PrjPcb, Power_Input.SchDoc, Power_Supply.SchDoc]
2019-07-10 Added PCB DOC
    [PowerSupply.PcbDoc, PowerSupplyPCBV1.PrjPcb, Power_Supply.SchDoc]
2019-07-12 Added Foot Prints
    [Power_Supply.SchDoc]
2019-07-12 More Footprints
    [Major Parts.xlsx, Power_Supply.SchDoc]
2019-07-13 Done adding footprints
    [Major Parts.xlsx, Power_Supply.SchDoc]
2019-07-14 Added BOM and current DAC circuit
    [PowerSupply.PcbDoc, PowerSupplyPCBV1.PrjPcb, PowerSupplyPCBV1_BOM.xlsx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]
2019-07-15 Done General placement
    [PowerSupplyPCBV1.PrjPcb, Power_Supply.SchDoc]
2019-07-17 Layout update
    [Power_Supply.SchDoc]
2019-07-18 More layouts
    [Power_Supply.SchDoc]
2019-07-20 Done Silkscreen clean up/DRC
    [PowerSupplyPCBV1.PrjPcb, Power_Supply.SchDoc]
2019-07-21 Ready for fab
    [Power_Supply.SchDoc]
2019-07-21 Added Mechnical 3D models
    [Power_Supply.SchDoc]
2019-08-23 Added Fab PCB scans
2019-09-07 Updated purchasing BOM
    [PowerSupplyPCBV1_BOM.xlsx]
